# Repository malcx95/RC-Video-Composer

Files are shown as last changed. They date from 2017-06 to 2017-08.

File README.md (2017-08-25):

# RC Video Composer

This project involves putting a Raspberry PI Zero on a 1:8th scale R/C
nitro powered buggy. This Raspberry PI records video while collecting sensor
data from a Teensy LC, which records the speed of the car the throttle and steering servo positions. The video and
sensor data are then fed through a python script which composes the data
into a video with the sensor data visualised.

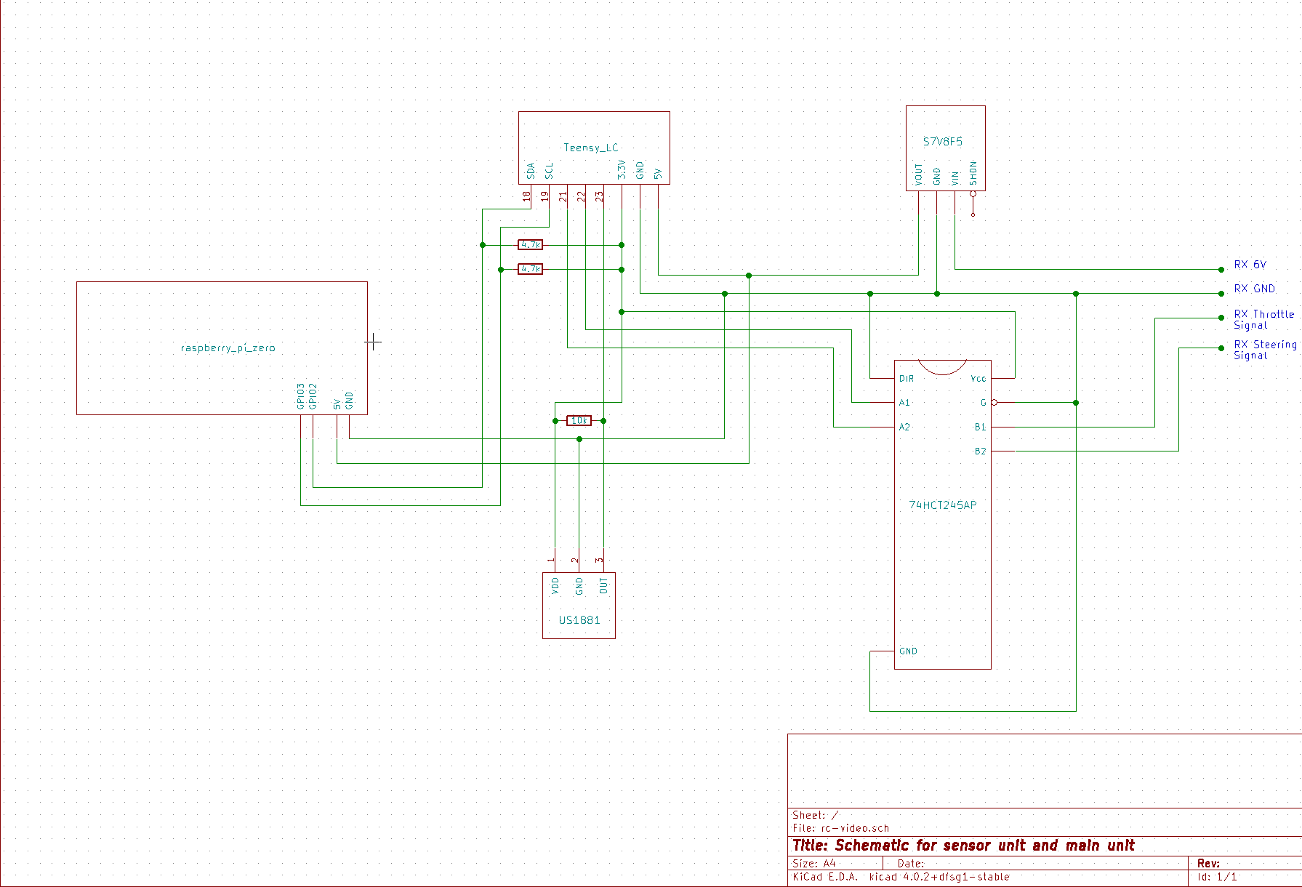
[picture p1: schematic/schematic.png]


I finished programming the Raspberry Pi and the Teensy and got everything to work. However when test driving
the actual car, the Pi kept dying whenever I hit something, so no recordings survived. Also the
magnets on the driveshaft and the sensor I was using to record speed were lost during driving.

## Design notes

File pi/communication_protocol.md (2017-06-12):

# Sensor data request

This is sent from Teensy to Pi whenever Pi requests data:

| Byte  | Content |
|:-----:| --- |
| 1 | Speed (km/h) |
| 2 | Steering value (0-255)|
| 3 | Throttle value (0-255)|

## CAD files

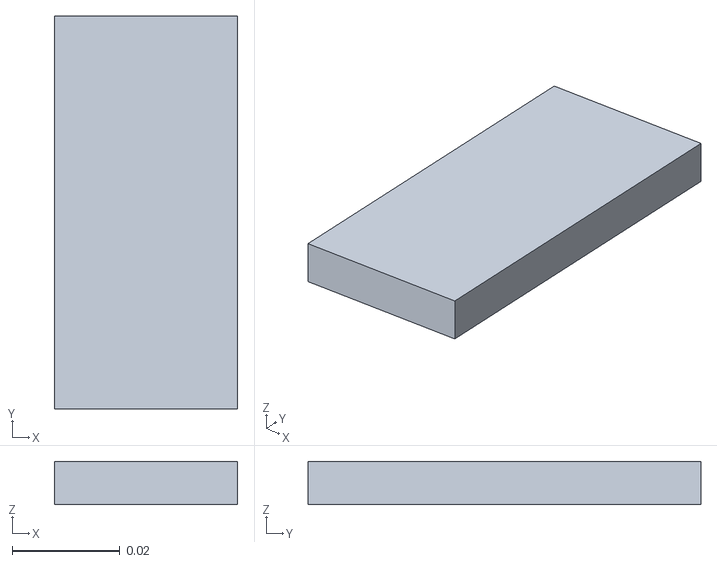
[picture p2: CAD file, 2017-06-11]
case/lid_teensy.stl
0.034 x 0.073 x 0.008

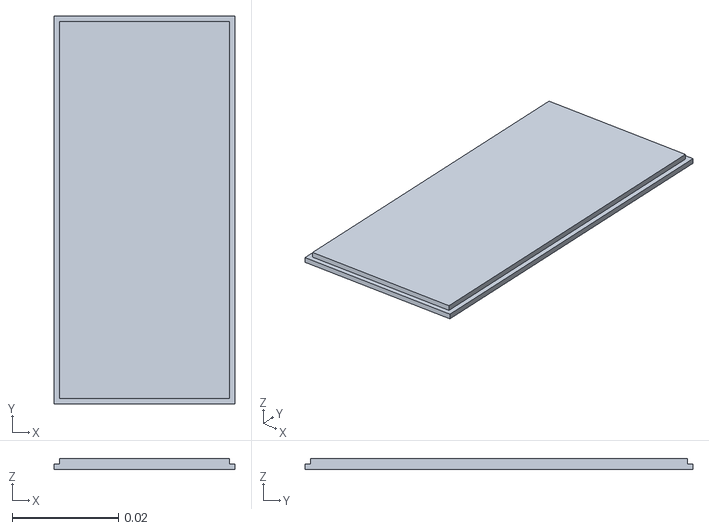
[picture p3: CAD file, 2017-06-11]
case/bottom_plate_pi.stl
0.034 x 0.073 x 0.002

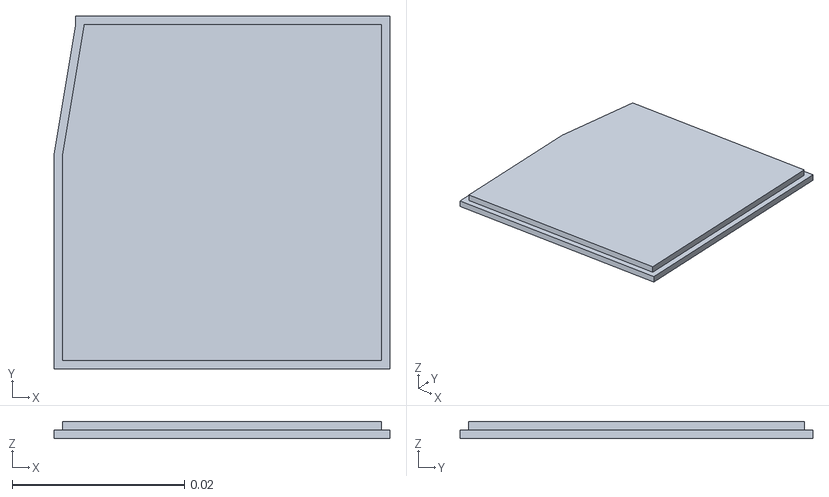
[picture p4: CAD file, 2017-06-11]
case/bottom_plate_teensy.stl
0.039 x 0.041 x 0.002

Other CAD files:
case/case.blend

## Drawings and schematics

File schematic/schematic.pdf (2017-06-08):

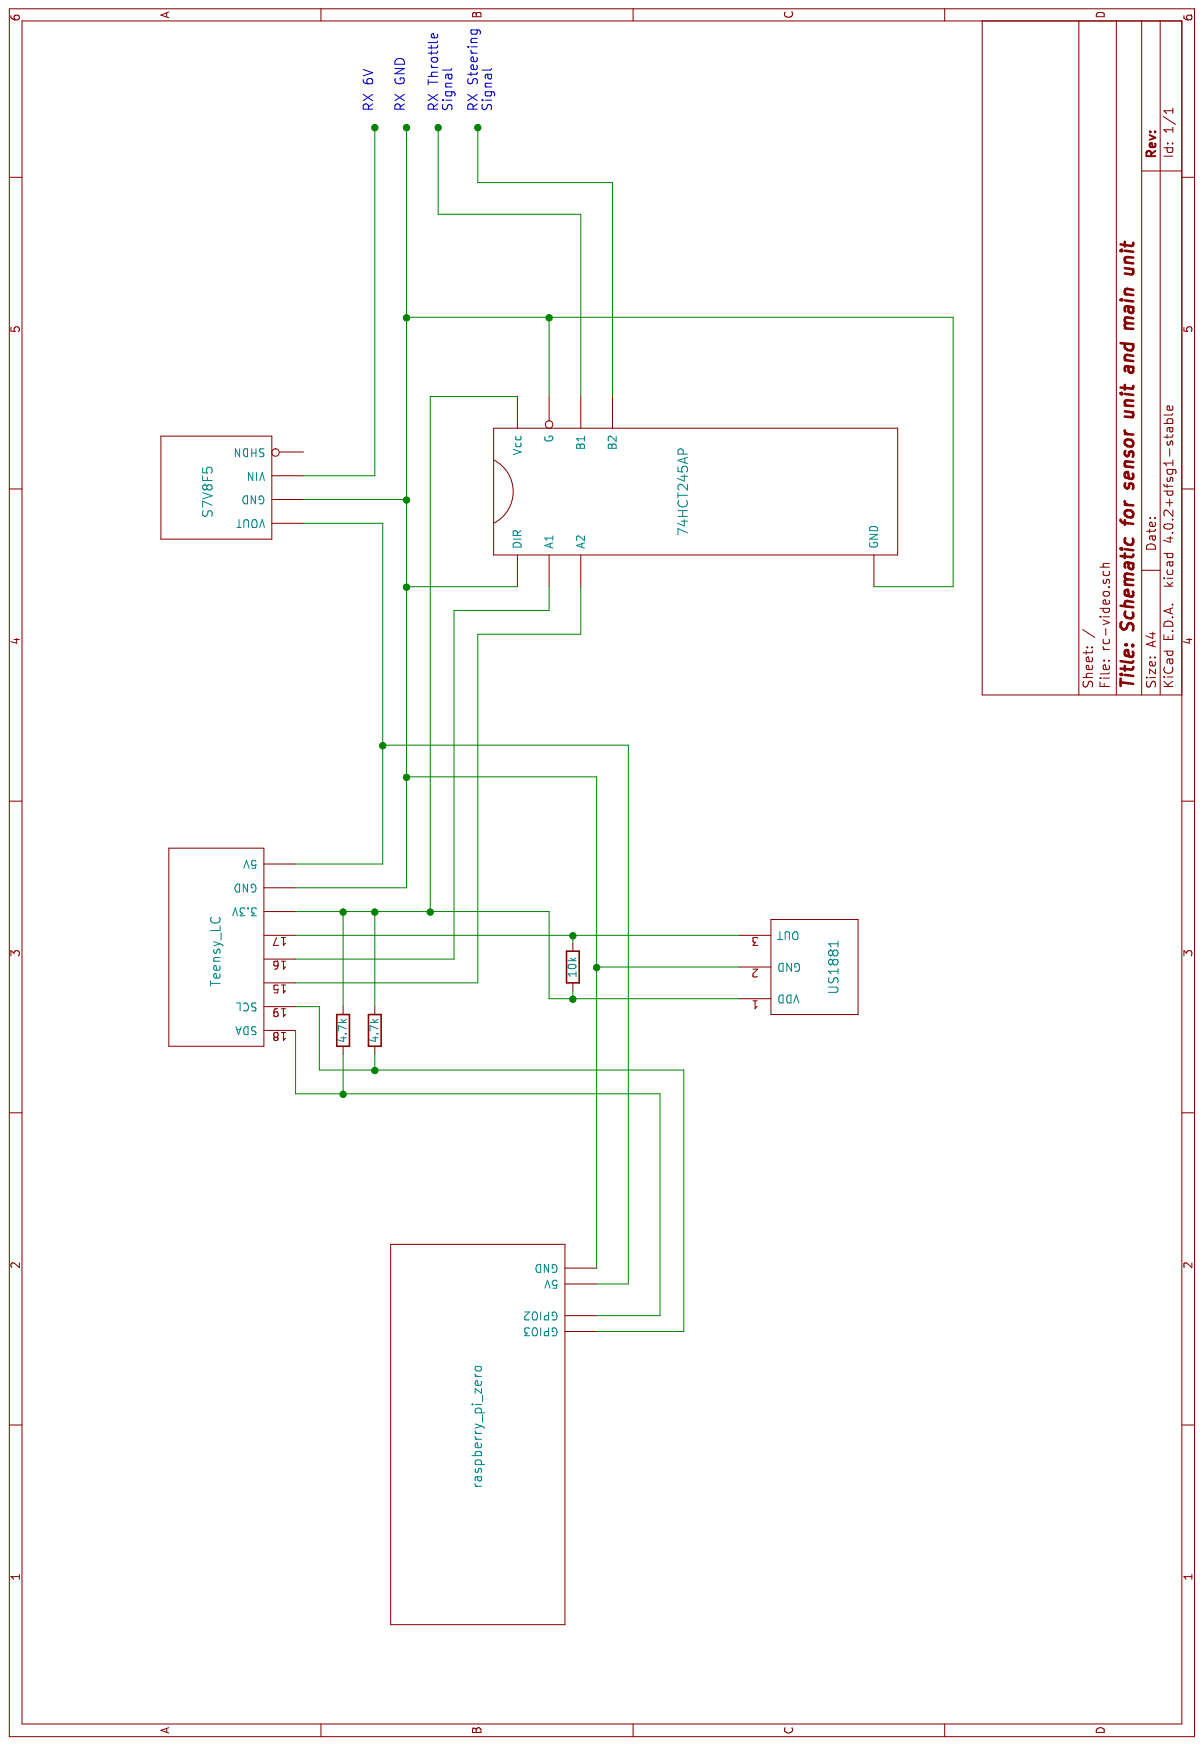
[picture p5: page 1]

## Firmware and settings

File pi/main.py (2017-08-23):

#!/usr/bin/python3

from datetime import datetime
import RPi.GPIO as GPIO
import time
import smbus
import os
import picamera

OUTPUT_DIR = "/home/pi/recordings"

SENSOR_UNIT_ADDRESS = 0x66
SENSOR_DATA_LENGTH = 3
SENSOR_DATA_PRINT_FORMAT = "Speed: {} km/h\nSteering: {}\nThrottle: {}"
SENSOR_DATA_FILE_FORMAT = "{speed},{steering},{throttle},{elapsed}"

LED_GREEN = 26
LED_YELLOW1 = 19

# This LED doesn't work :(
# LED_YELLOW2 = 20

LED_YELLOW2 = 17
LED_RED = 14
BUTTON_PORT = 21


def setup_output_dir():
    if not os.path.exists(OUTPUT_DIR):
        os.makedirs(OUTPUT_DIR)


def button_pressed():
    """
    Returns whether someone is pressing the button.
    """
    return not GPIO.input(BUTTON_PORT)


def record(camera):

    recording_dir = os.path.join(
        OUTPUT_DIR,
        datetime.now().strftime("%Y%m%d-%H%M%S"))
    os.makedirs(recording_dir)

    sensor_values = {}

    bus = smbus.SMBus(1)
    
    start_datetime = datetime.now()

    camera.start_recording(os.path.join(recording_dir, "video.h264"))
    start_time = time.time()

    while not button_pressed():
        try:
            speed, steering, throttle = bus.read_i2c_block_data(
                SENSOR_UNIT_ADDRESS, 0, SENSOR_DATA_LENGTH)

            sensor_values[time.time() - start_time] = (speed, 
                                                       steering,
                                                       throttle)

        except (IOError, TimeoutError, OSError):
            continue
        time.sleep(0.02)
    camera.stop_recording()

    with open(os.path.join(recording_dir, "sensor.csv"), 'w') as output:
        output.write(start_datetime.strftime("%Y,%m,%d,%H,%M,%S,%f"))
        for t in sorted(sensor_values.keys()):
            speed, steering, throttle = sensor_values[t]
            data_packet = SENSOR_DATA_FILE_FORMAT.format(
                speed=speed, steering=steering, throttle=throttle, 
                    elapsed=t)
            output.write(data_packet + '\n')


def i2c_test():
    bus = smbus.SMBus(1)
    # bus.write_block_data(0x66, 0, [2, 32, 1, 0, 23])
    try:
        while not button_pressed():
            start = time.time()
            try:
                data = bus.read_i2c_block_data(SENSOR_UNIT_ADDRESS,
                                               0, SENSOR_DATA_LENGTH)
                print(data)
            except (IOError, TimeoutError, OSError):
                pass
            time.sleep(0.02)
            print("")
            print("Time: " + str(time.time() - start))
            print("")
    except KeyboardInterrupt:
        pass
    finally:
        bus.close()


def countdown():
    """
    Blinks the green and yellow leds three times. 
    Cancels if button is pressed. Returns False if cancelled,
    True otherwise.
    """

    GPIO.output(LED_GREEN, False)

    time.sleep(1)

    for led in [LED_GREEN, LED_YELLOW1, LED_YELLOW2]:
        for i in range(6):
            time.sleep(0.5)

            if button_pressed():
                GPIO.output(led, False)
                return False

            GPIO.output(led, (i + 1) % 2)

    time.sleep(0.5)
    return True


def main():

    GPIO.setmode(GPIO.BCM)

    GPIO.setup(LED_RED, GPIO.OUT)
    GPIO.setup(LED_GREEN, GPIO.OUT)
    GPIO.setup(LED_YELLOW1, GPIO.OUT)
    GPIO.setup(LED_YELLOW2, GPIO.OUT)

    GPIO.setup(BUTTON_PORT, GPIO.IN, pull_up_down=GPIO.PUD_UP)

    setup_output_dir()

    with picamera.PiCamera(resolution="1920x1080", framerate=25) as camera:

        while True:

            # Standby mode

            GPIO.output(LED_GREEN, True)
            GPIO.output(LED_RED, False)

            if button_pressed():
                if countdown():
                    GPIO.output(LED_RED, True)
                    record(camera)
                    GPIO.output(LED_RED, False)
                    time.sleep(1)

            time.sleep(0.1)


    # setup()
    # record()
    # i2c_test()
    # camera = picamera.PiCamera()
    # try:
    #     camera.start_recording('test.h264')
    #     while True:
    #         time.sleep(1)
    # except KeyboardInterrupt:
    #     camera.stop_recording()


if __name__ == "__main__":
    try:
        main()
    finally:
        GPIO.cleanup()

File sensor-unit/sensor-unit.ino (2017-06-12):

#include "pwmread.h"
#include "speed.h"
#include <stddef.h>
#include <stdint.h>
#include <i2c_t3.h>

const int I2C_ADDRESS = 0x66;
const int I2C_FREQ = 10000;
const int MESSAGE_LENGTH = 3;

PWMStatus throttle;
PWMStatus steering;

int i;

void setup() {

    pinMode(13, OUTPUT);

    Serial.begin(9600);

    digitalWrite(13, HIGH);
    delay(1000);
    digitalWrite(13, LOW);

    speed_setup();

    pwm_read_setup(16, &throttle, 0);
    pwm_read_setup(15, &steering, 0);

    communication_setup();

    i = 0;

}

void loop() {

    i++;

    update_pwm(16, &throttle);
    update_pwm(15, &steering);

    if (i % 50000 == 0) {
        Serial.println(get_rpm());
    }

    digitalWrite(13, digitalRead(17));

}

void communication_setup() {
    Wire.begin(I2C_SLAVE, I2C_ADDRESS, I2C_PINS_18_19,
               I2C_PULLUP_EXT, I2C_FREQ);
    Wire.onRequest(on_request);
    Wire.onReceive(on_command);
}

void on_request() {
    digitalWrite(13, HIGH);
    uint8_t message[MESSAGE_LENGTH];
    message[0] = get_speed();
    message[1] = get_current_value(&steering);
    message[2] = get_current_value(&throttle);
    Wire.write(message, MESSAGE_LENGTH);
    digitalWrite(13, LOW);
}

void on_command(size_t num_bytes) {
    
}

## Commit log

2017-05-31 Added sensor unit directory and got rpm measurement working
2017-06-02 Got PWM measurement working
2017-06-04 Got i2c communication basically working
2017-06-05 Updated README, moved communication to ino, added things to pwm read
2017-06-07 Added get_value function in pwmread and added comprotocol
2017-06-07 Implemented data requests, succeeded in sending real pwm-data and speed over i2c
2017-06-08 Added schematic and decided that the temperature sensor was dumb
    [rc-video.sch]
2017-06-08 Changed some pins and added schematic pdf
2017-06-10 Added teensy case and gitignore
    [case.blend]
2017-06-11 Finished modeling cases and added stls
    [bottom_plate_pi.stl, bottom_plate_teensy.stl, case.blend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]
2017-06-11 Added scaled blender file
    [case.blend]
2017-06-11 Flip normals
    [bottom_plate_pi.stl, bottom_plate_teensy.stl, case.blend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]
2017-06-12 Removed temperature from communication protocol
2017-06-17 Started on the process of recording sensor data on the pi
2017-07-04 Added code for recording video alongside sensor data
2017-08-12 Added the button, the LEDs and countdown
2017-08-14 Created a steering mask function
2017-08-15 Implemented sensor data reading, kind of works
2017-08-16 Steering bar pretty much works, throttle bar almost works. Abandoned masks
2017-08-17 Throttle and steering bars are now working fine
2017-08-17 Added guiding bars, repositioned control bars, fixed padding
    [main.py]
2017-08-23 Fixed synchronization bug and other things, ready for testdrive
    [main.py]
